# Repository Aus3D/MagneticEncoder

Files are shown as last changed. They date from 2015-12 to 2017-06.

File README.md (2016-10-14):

# MagneticEncoder
## Overview
The magnetic breakout is a breakout PCB for the AMS AS5311 magnetic encoder IC, for testing and development purposes. An external microcontroller is required to track the encoder's position.

The magnetic module combines the features of the breakout board along with an on-board AVR tasked with reading the encoder data and tracking the encoder's position. It exposes the tracked position over an I2C interface.

AMS have now discontinued the AS5311 IC I have been using, so I am switching to the NSE5310 - which I believe AMS intend as a replacement for the AS5311, as it has very similar capabilities. The NSE5310 module is still untested however.

## Open Source
In the spirit of the RepRap project, the magnetic encoder module is fully open source - files to manufacture or modify a board of your own are included in this repository. This project is licensed under a GPLv3 license, and anyone is free to modify it, manufacture it, sell it - as long as you share your modifications under the same license, we're good!

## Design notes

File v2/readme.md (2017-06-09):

## Improvements in V2:

- Full 3V/5V compatibility
  - Power can be either, I2C signals can be either. All combinations are valid, i.e.:
    - 5V Power, 5V I2C
    - 5V Power, 3.3V I2C
    - 3.3V Power, 5V I2C
    - 3.3V Power, 3.3V I2C
  - No solder jumpers to set voltage, works automatically.
- Continuous voltage input range
  - Previously 3.3V-3.6V in 3.3V mode, 4.5-5.5V in 5V mode
  - Now 3.3V – 5.5V, no ‘modes’
- Modules are now ‘Chainable’
  - Each module has 3 JST-SH sockets on board, modules can be daisy-chained to reduce wiring clutter
  - May remove need for splitter boards in some printer layouts
- Overvoltage protection
  - Protected against supply voltages > 5.5V and < 15V, i.e. 12V will not damage the module but it will not operate in this condition.
- Reverse polarity protection
  - Protected against accidentally reversing VDD and GND pins in connector. Reversal will not damage the module but it will not operate in this condition.
- Overcurrent protection
- DIP switches instead of solder jumpers
  - Easy to set module address via switch positions
  - No longer necessary to cut/solder jumpers
  - Easily changeable/reversible
  - Configuration via I2C is still possible if preferred
- Faster on-board microcontroller
  - STM32F030F4P6 instead of ATmega328-AU
  - Possibility for averaging/filtering readings on-board

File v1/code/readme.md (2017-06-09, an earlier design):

The code for the magnetic encoder modules has been moved to its own repository [here](https://github.com/Aus3D/Magnetic-Encoder-Firmware).

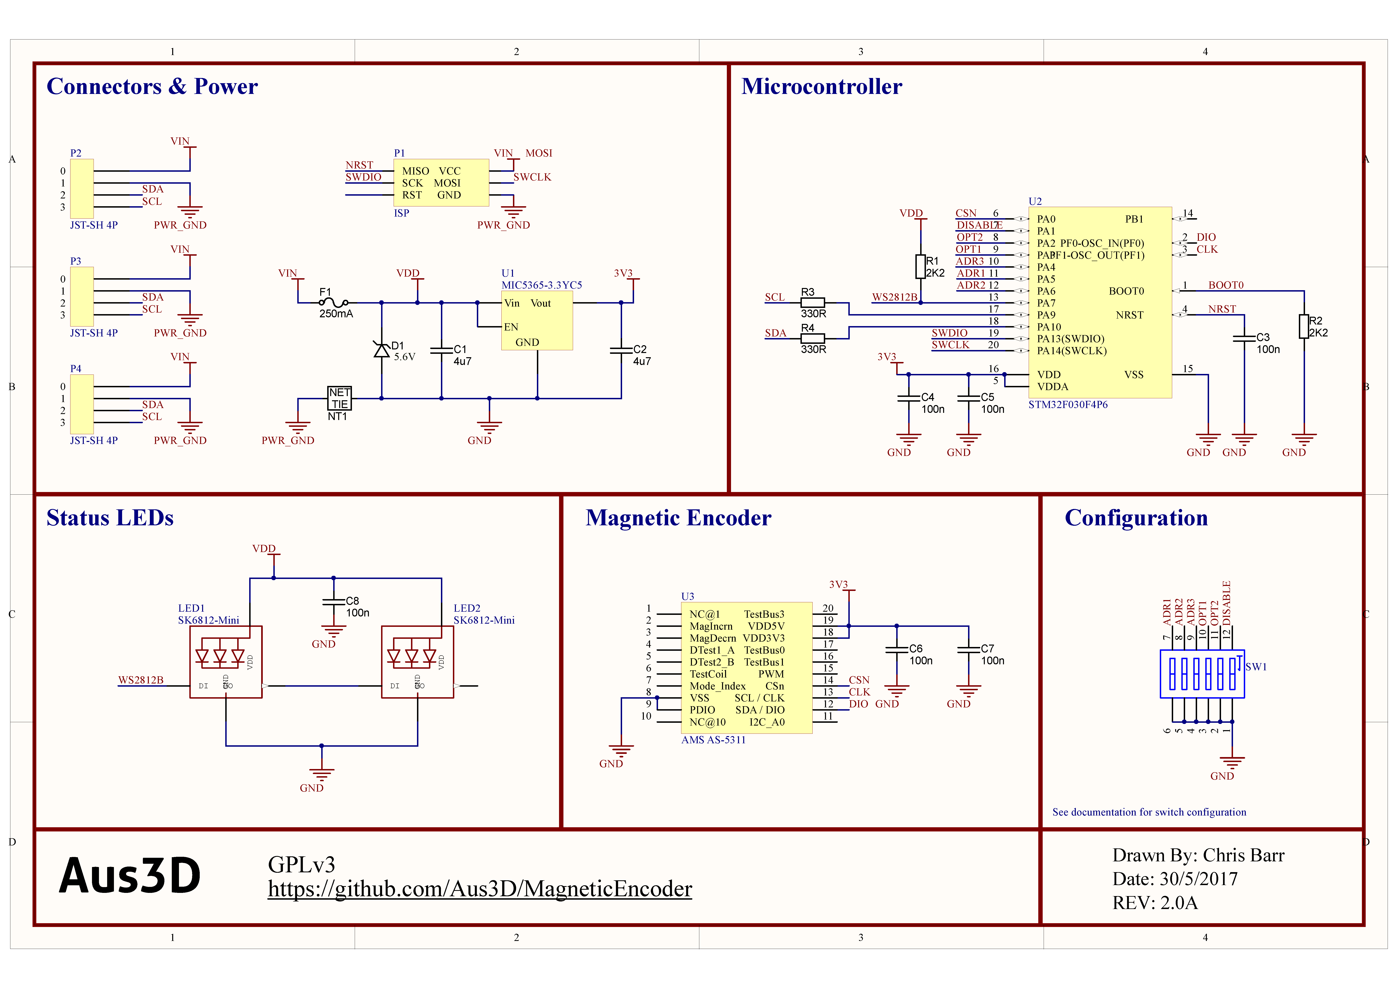
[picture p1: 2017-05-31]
v2/pcb/schematic-mag-encoder-v2.png

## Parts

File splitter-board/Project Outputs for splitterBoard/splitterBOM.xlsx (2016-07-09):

Designator | Description | Comment | Quantity | Manufacturer 1 | Manufacturer Part Number 1 | Supplier 1 | Supplier Part Number 1
P1, P2, P3, P4, P5, P6, P7 | Header, 4-Pin | Approved Sub OK | 7 | 3M (https://octopart-clicks.com/click/altium?sku=3M9447-ND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) | 961104-6404-AR | Digi-Key | 3M9449-ND

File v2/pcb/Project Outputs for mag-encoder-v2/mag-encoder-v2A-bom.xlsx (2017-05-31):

Designator | Description | Comment | Manufacturer 1 | Manufacturer Part Number 1 | Quantity | Supplier 1 | Supplier Part Number 1 | Value
C1, C2 | Capacitor SMD Cer 4.7uF 10% 16V X5R 0603 | Approved sub OK | Samsung Electro-Mechanics America, Inc. | CL10A475KO8NNNC | 2 | Digi-Key | 1276-2087-1-ND | 4u7
C3, C4, C5, C6, C7, C8 | Capacitor SMD Cer 100nF 10% 16V X5R 0402 | Approved sub OK | AVX Corporation | 0402YD104KAT2A | 6 | Digi-Key | 478-1126-1-ND | 100n
D1 | Diode Zener SMD 5.6V 0.5W SOD-123 BZT52C5V6 | Approved sub OK | Diodes Incorporated | BZT52C5V6-7-F | 1 | Digi-Key | BZT52C5V6-FDICT-ND | 5.6V
F1 | Fuse - 15V 100mA Hold 250mA Trip PTC SMD 0603 | Approved sub OK | Bel Fuse Inc. | 0ZCM0010FF2G | 1 | Digi-Key | 507-1818-1-ND | 250mA
LED1, LED2 | RGB Smart LED WS2812 / SK6812 Mini 3535 | SK6812-Mini | DONGGUANG OPSCO OPTOELECTRONICS CO., LTD | SK6812MINI | 2
P2, P3, P4 | JST SH 4P Connector | JST-SH 4P | JST Sales America Inc. | SM04B-SRSS-TB(LF)(SN) | 3 | Digi-Key | 455-1804-1-ND
R1, R2 | Resistor SMD chip 2.2k Ohm 0.063W 5% 0402 | Approved sub OK | Vishay Dale | CRCW04022K20JNED | 2 | Digi-Key | 541-2.2KJCT-ND | 2K2
R3, R4 | Resistor SMD chip 330 Ohm 0.063W 5% 0402 | Approved sub OK | Yageo | RC0402JR-07330RL | 2 | Digi-Key | 311-330JRCT-ND | 330R
SW1 | SMD DIP Switch 1.27mm Pitch 6 Position | Approved sub OK | TE Connectivity ALCOSWITCH Switches | 1571983-9 | 1 | Digi-Key | 450-1950-1-ND
U1 | 3.3V LDO Regulator | MIC5365-3.3YC5 | Microchip Technology | MIC5365-3.3YC5-TR | 1 | Digi-Key | 576-3193-1-ND
U2 | ARM Cortex-M0 32-bit MCU, 16 KB Flash, 4 KB Internal RAM, 15 I/Os, 20-pin TSSOP, -40 to 85 degC, Tube | STM32F030F4P6 | STMicroelectronics (https://octopart-clicks.com/click/altium?sku=511-STM32F030F4P6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) | STM32F030F4P6 (https://octopart-clicks.com/click/altium?sku=511-STM32F030F4P6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) | 1 | Digi-Key | 497-14044-5-ND (https://octopart-clicks.com/click/altium?sku=511-STM32F030F4P6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)
U3 | AMS Linear Magnetic Encoder IC | AMS AS-5311 | ams | AS5311-ATST-500 | 1 | Digi-Key | AS5311-ATST-500CT-ND

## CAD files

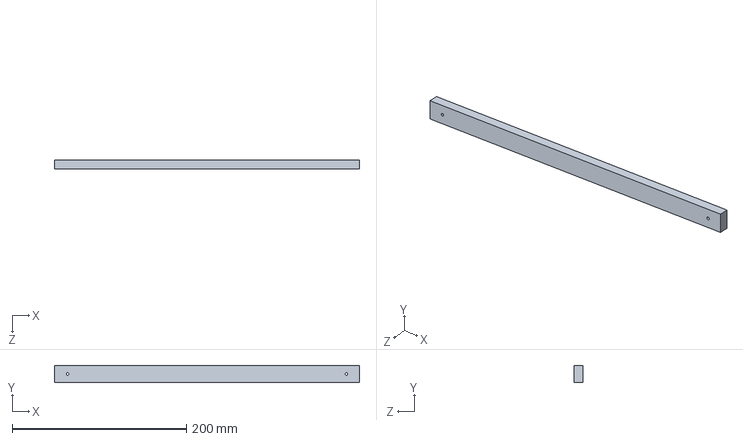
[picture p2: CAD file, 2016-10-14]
hardware/mountingBar.SLDPRT
350.0 x 20.0 x 10.0 mm

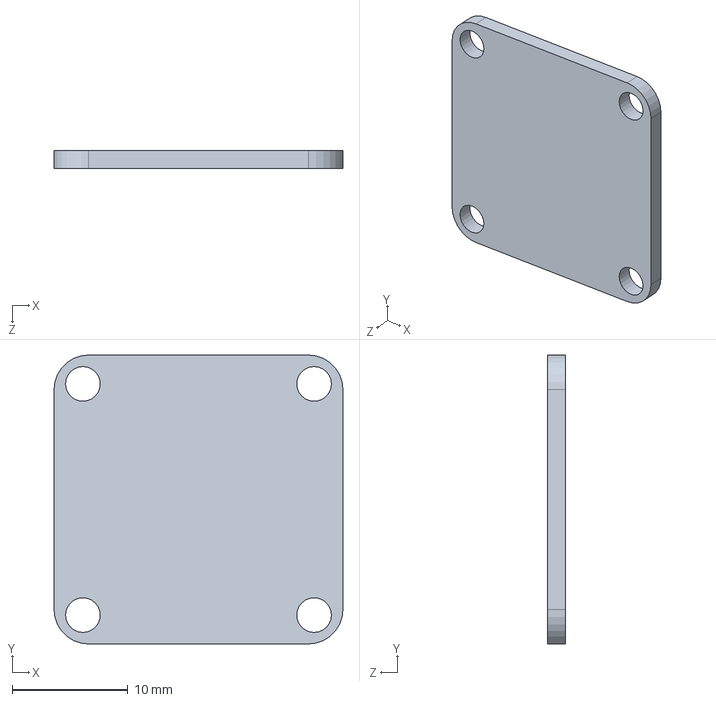
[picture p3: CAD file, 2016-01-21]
hardware/placeholderPart.SLDPRT
25.0 x 25.0 x 1.60 mm

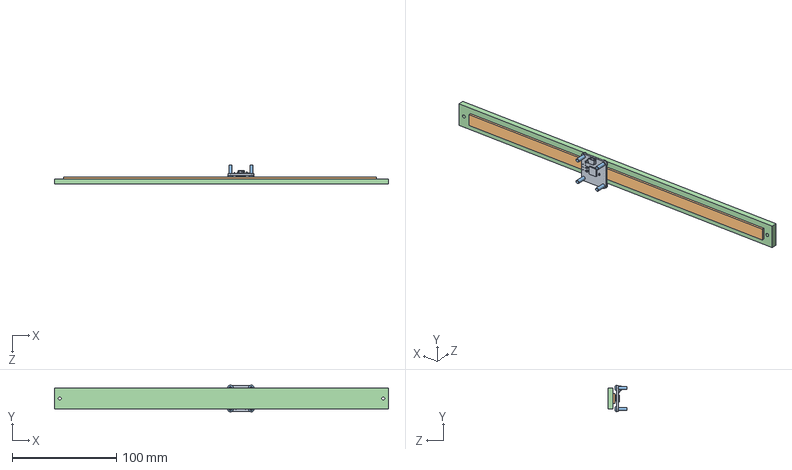
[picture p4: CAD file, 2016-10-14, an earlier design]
v1/nse5310-module-pcb/mounting-demo-assembly.SLDASM
320.0 x 25.7 x 18.5 mm
nse5310-module
mag-strip-placeholder
socket button head screw_iso x 4
mag-strip-support-placeholder

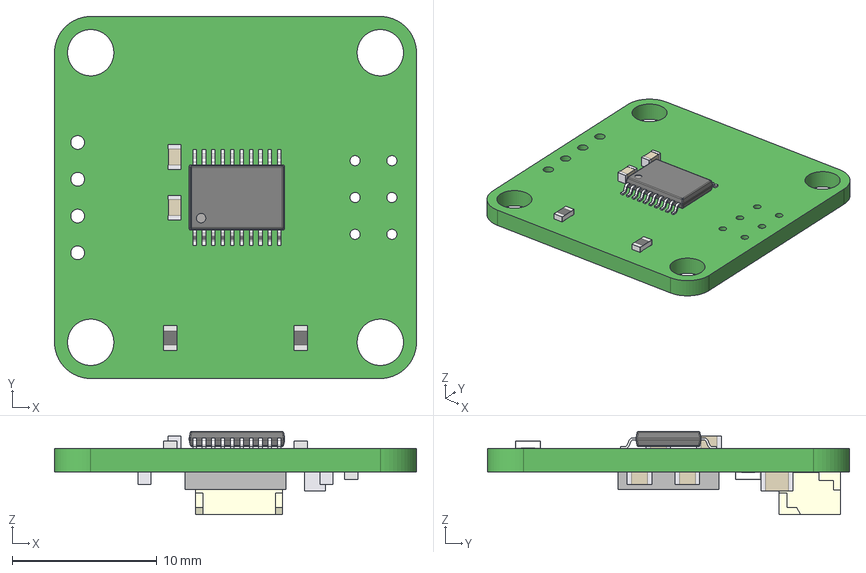
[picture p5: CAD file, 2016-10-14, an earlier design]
v1/nse5310-module-pcb/nse5310-module.step
25.0 x 25.0 x 5.76 mm
Board
RES_0603_(1608_metric) x 3
Extruded
CAP_0603 x 5
SM04B-SRSS-TB_RGB13434879
CAP_0805

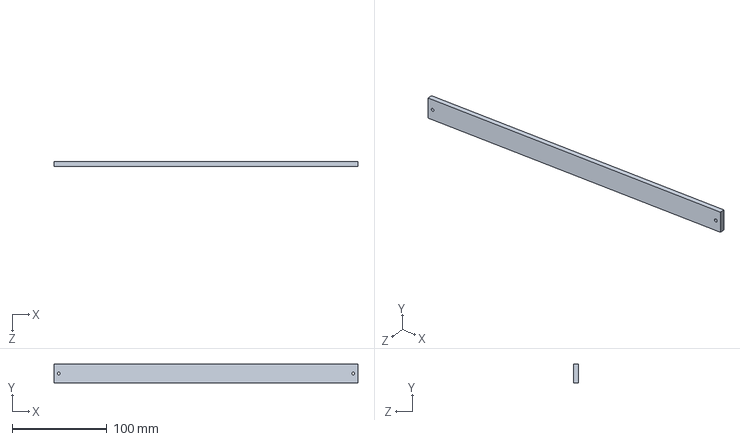
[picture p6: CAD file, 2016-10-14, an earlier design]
v1/nse5310-module-pcb/mag-strip-support-placeholder.SLDPRT
320.0 x 20.0 x 5.00 mm

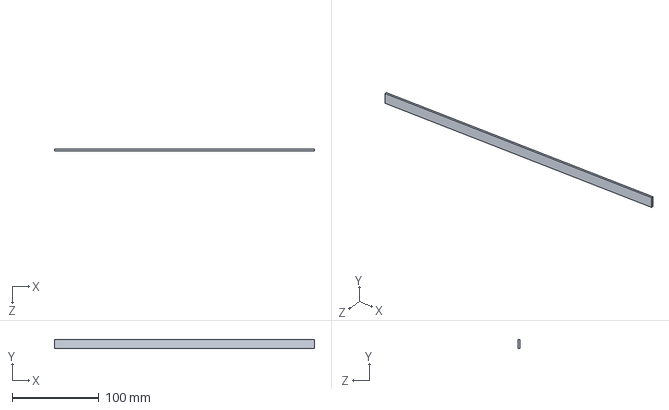
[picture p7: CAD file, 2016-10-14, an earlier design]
v1/nse5310-module-pcb/mag-strip-placeholder.SLDPRT
300.0 x 10.0 x 2.00 mm

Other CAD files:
v1/nse5310-module-pcb/mounting-demo-assembly.SLDDRW
v1/nse5310-module-pcb/nse5310-module.SLDPRT

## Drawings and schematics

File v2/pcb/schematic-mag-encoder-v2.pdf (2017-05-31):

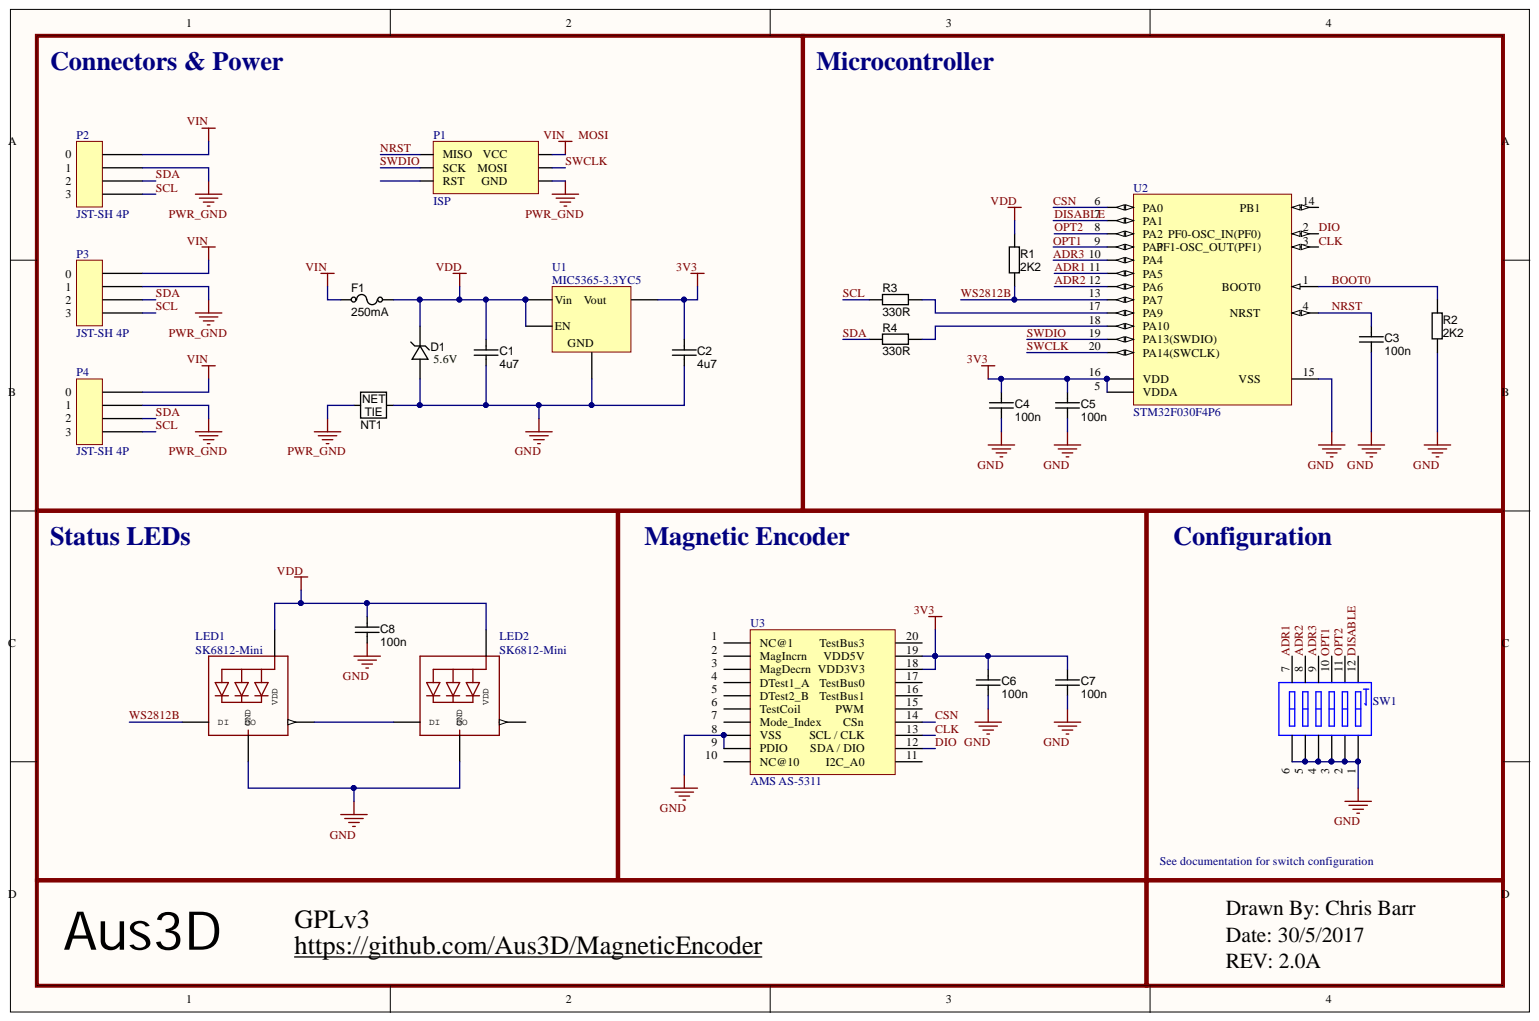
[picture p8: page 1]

SWDIO

See documentation for switch configuration

https://github.com/Aus3D/MagneticEncoder

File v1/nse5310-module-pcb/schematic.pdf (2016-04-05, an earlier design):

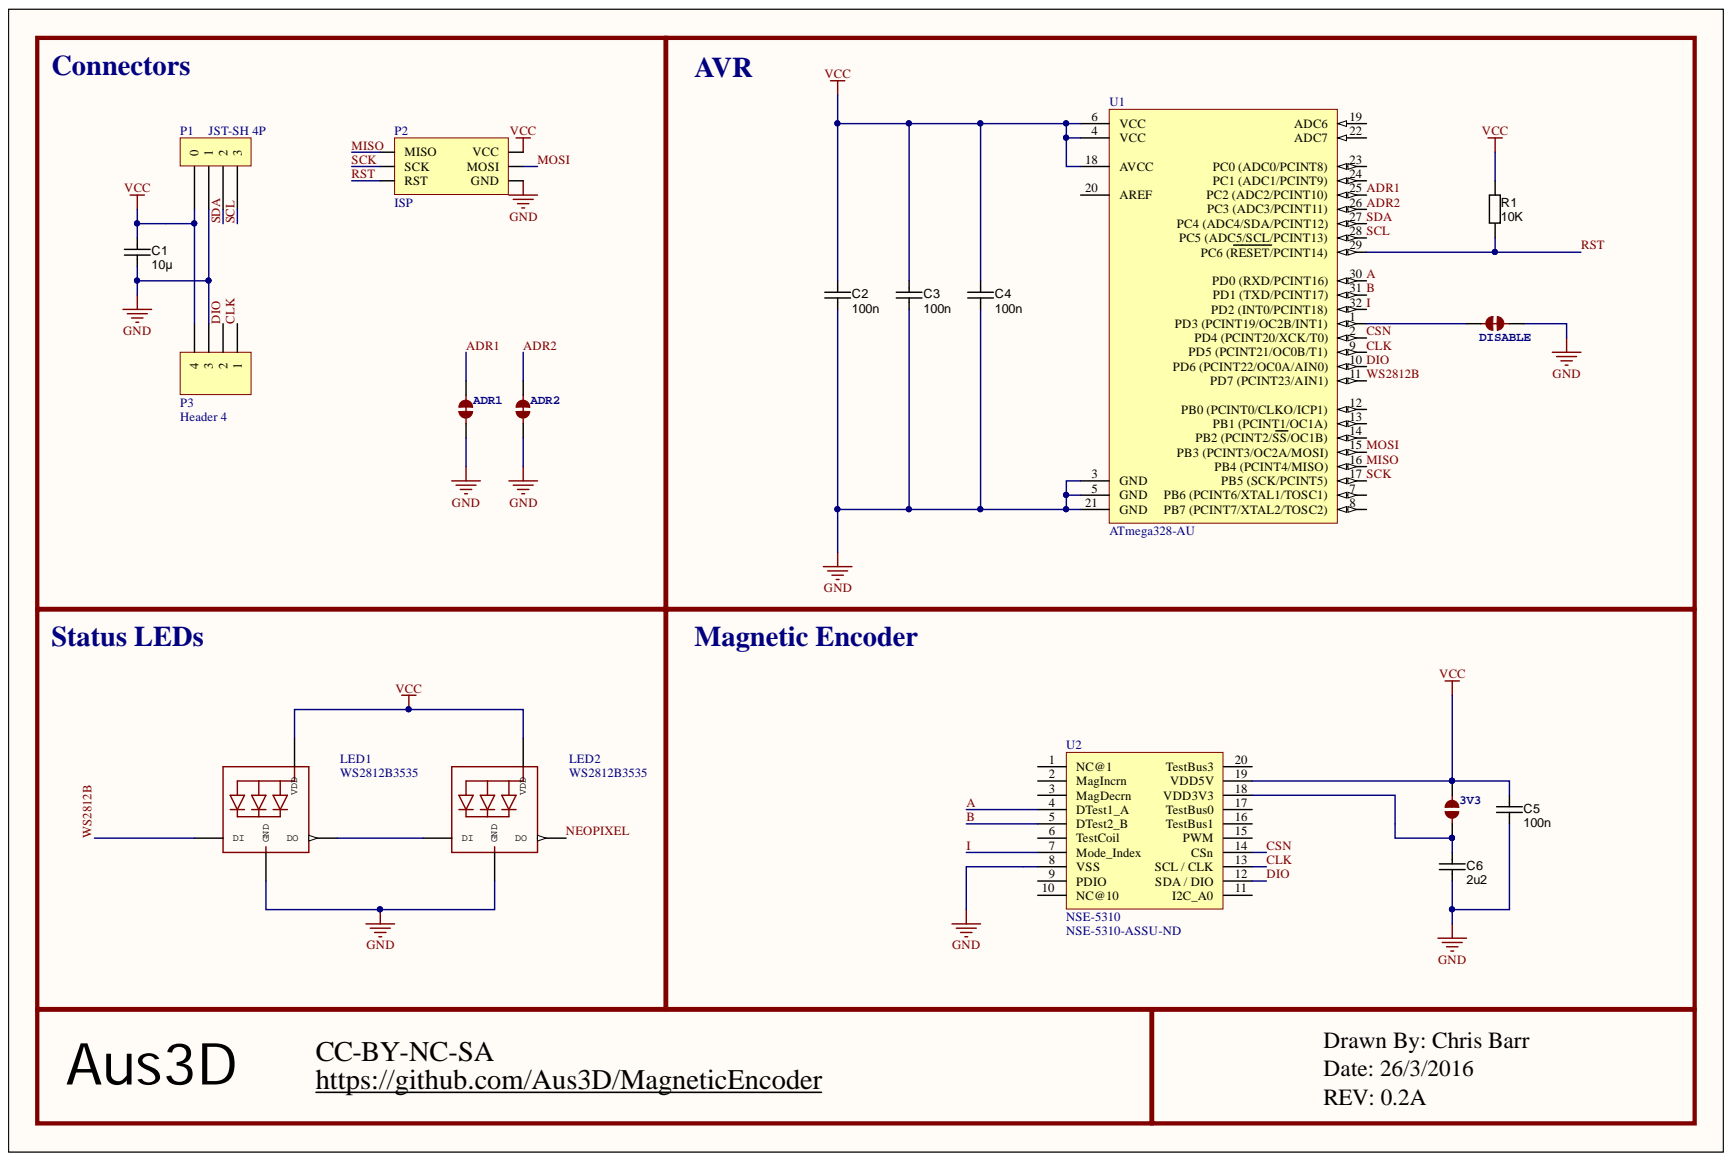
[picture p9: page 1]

P1 JST-SH 4P P2 VCC | VCC

VSS 8
PDIO 9

https://github.com/Aus3D/MagneticEncoder

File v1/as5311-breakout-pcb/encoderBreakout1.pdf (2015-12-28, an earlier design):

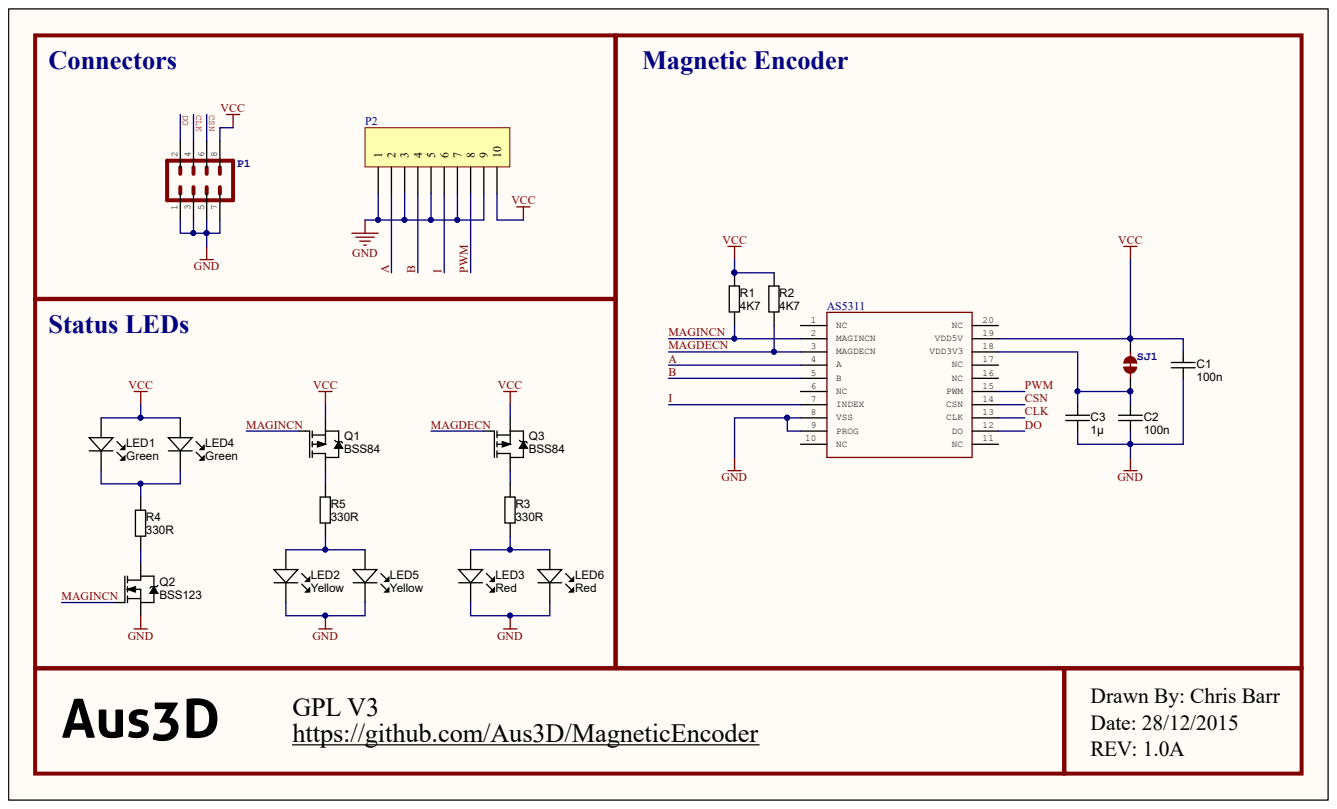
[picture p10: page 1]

https://github.com/Aus3D/MagneticEncoder

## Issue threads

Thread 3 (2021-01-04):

Q - AS5600 magnetic encoder

DrumClock, 2021-01-04:
Hi, is it possible to use this magnetic encoder for Marlin FW?

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

Thanks :)

Fusseldieb, 2021-08-10:
Same question

Fusseldieb, 2022-01-30:
Why did you close the issue @DrumClock ?

DrumClock, 2022-01-30:
Nobody was interested in over a year, so why leave it open ... It doesn't make sense.

jwdriessen, 2022-05-05:
I would love to know how to set this up with marlin 2.0.
I have set up this encoder and try to test it with moving the X motor and holding the axis firmly
I would expect that the encoder makes up for the missed steps but that is not happening.
Is there anyone out there who has this working with a NEMA 17 motor?
Regards JWD

theohenrichs, 2022-06-01:
Hi jwdriessen

Reading https://github.com/MarlinFirmware/Marlin/issues/21138 it seems that Marlin doesn't support this type of position-thing at all anymore .....

Quote from DrumClock @ 21 Feb 2021

> That's probably why Aus3D ended up with the production of its module, and the function in Marlin is just a remnant that is no longer used.

Endquote ...

chrissbarr, 2022-06-26:
Hi all,

Sorry that there's been no proper reply here before.

The AS5600 is a fairly different type of encoder to the one that was used in these modules. I did not write any Marlin firmware feature to support encoders like the AS5600. I had planned to, but do not believe it ever made it to a working state. Others may have done so, but I am unsure.

Additionally, the encoder modules in this repo (and supported by the Marlin code I wrote) were implemented with an onboard AVR microcontroller that managed each encoder IC. The AVR firmware implemented a slave I2C interface that Marlin communicated with (e.g., the Marlin FW never directly touched the encoder IC's I2C interface). This was done because each encoder needed to be read at a higher rate than was practical from the central Marlin FW (it also allowed the use of different I2C addresses, and the implementation of a checksum to add some noise tolerance to the long I2C bus).

So, if you want to directly talk to the AS5600 using I2C from Marlin, you should ignore the work I did previously.

The error correction behaviour itself that I added to Marlin could definitely be adapted to the AS5600 (or any other comparable encoder).

**So, in short, I would say**: there is no reason the AS5600 couldn't be used in Marlin, but the I2C-related code I wrote will not be helpful, and I don't know if anyone else has written something suitable. There may be issues relating to the required update-rate, noise tolerance, and I2C address selection. If the I2C interface can be implemented, the error-correction code I added can likely be adapted. However I don't think there is any simple configuration option to enable the desired behaviour - someone would need to implement it.

Aus3D stopped producing these encoder modules for two reasons:

1. The total cost to upgrade a printer with the linear encoders was quite high (around 60 USD per axis, so say 180 USD per printer) - there did not seem to be a lot of demand at this price point.
2. The encoder IC we were using (NSE5310 or AS5311) went out of stock for over a year and we were unable to produce any more modules.

I hope that sheds some clarity on this topic. Sorry that I'm not adding any positive news here. Happy to answer any further questions though.

Closed 2022-01-30.

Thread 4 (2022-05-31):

M860-M869 - I2C Position Gcode commands

theohenrichs, 2022-05-31:
I have connected an AS5600 magnetic encoder to a Rumba32 board and configured it as mentioned in the configuration-adv.h (Marlin 2.0.9.3).
Carefully I started with only the X. No errors occurred during the building, uploading, and startup of the printer.

When I wanted to check the status of the AS5600 with the Gcode command M862 X, the response of the board was:  **"echo:Unknown command: "M862 X"**
I have tried all **M860-M869 - I2C Position commands**, but each time the answer is: **"echo:Unknown command"**.
I double checked the connections "+, -, D and C" both on the board and on the AS5600.

However, something is wrong here, is it that the **AS5600 is NOT compatible**, or is there perhaps a **bug in this Marlin version**?

Anyone have an idea what's going on here? Help is greatly appreciated!

theohenrichs, 2022-05-31:
Oh dear!
Reading https://github.com/MarlinFirmware/Marlin/issues/21138  it seems that Marlin doesn't support this type of position-thing at all anymore .....

Quote from DrumClock @ 21 Feb 2021

_> That's probably why Aus3D ended up with the production of its module, and the function in Marlin is just a remnant that is no longer used._

Endquote ...

Closed 2022-05-31.

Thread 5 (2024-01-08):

Closed loop doesn't work

RbAstra, 2024-01-08:
Hello

I want to control 3 axis by sending Grbl commands in the USB port by using pronterface software. I succeed to move every axis but I need to be sure of the position (closed loop).
So I rebuild 3 magnetic encoders (V1 with Atmega) by using the manufacturing files and soldering components on the PCB. I made some tests with the encoders and I can measure the position of the system but it didn't work in closed loop.
This is what I've done to verify closed loop function:
1. I send a GRBL command to make relative positioning -> G91 G0 X100
2. I block the system during movement (just like the video at the bottom of the encoder wiki)
3. Thanks to magnetic encoder I measure position in ticks at the end of movement and the reached distance was 97mm instead of 100mm

When I enable the correction (M867 command) it responds the correction is enabled for all axis. However it doesn't correct the position.

Does Somebody know why ?

RbAstra, 2024-01-08:
I'm using Marlin 2.1.2.1

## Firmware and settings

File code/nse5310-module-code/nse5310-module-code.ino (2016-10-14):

/*
/---------------------------------------------------------------/
 * Code for the Aus3D NSE5310 Magnetic Encoder I2C Module
 * Chris Barr, 2016
 * 
 * This module is designed to connect to a host device via I2C,
 * and report the current position as observed by the magnetic encoder.
 * 
 * The following I2C commands are implemented:
 *    
 * 1: Resets travelled distance to zero
 * 
 * 2: Sets this modules I2C address to the next byte received, 
 *    saves in EEPROM
 *    Module resets and rejoins bus with new address
 *    
 * 3: Set the information that will be sent on the next I2C request.
 *      0: Default, responds with encoder count
 *      1: Responds with magnetic signal strength
 *            0: Signal good, in range.
 *            1: Signal weak, edge of range (but probably usable)
 *            2: Signal weak / lost, edge / outside of range (probably not usable)
 *      2: Responds with firmware version + compile date / time
 *      3: Responds with raw encoder reading
 *
 * 4: Clear the settings saved in EEPROM, restoring all defaults
 *      Handy to return to hardware I2C address if required
 *      A power cycle will be required for settings to reset
 *
 * 10: Sets the mode of the LEDs based on the next two bytes received, 
 *     byte1 = led (0 or 1), byte 2 = mode (see below)
 *     saves in EEPROM
 *
 * 11: Sets the brightness of the LEDs based on the next two bytes received,
 *    byte1 = led (0 or 1), byte 2 = brightness (0-255)
 *    saves in EEPROM
 *
 * 12: Sets the RGB value for the LEDs to the next three bytes received,
 *     LEDs must still be set to RGB mode to display the sent value.
 *
 * 13: Sets the HSV value for the LEDs to the next three bytes received,
 *     LEDs must still be set to HSV mode to display the sent value.
 *
 * 14: Set the rate variable of the LEDs based on the next two bytes received,
 *      Rate is used in some of the different LED modes
 * 
 * I2C address can either be set over I2C (as shown above), or configured by cutting jumper traces on PCB.
 * If the address has been set by I2C, it can only be overridden by setting a new address over I2C, or by
 * sending the I2C command to reset the EEPROM.
 * 
 * 0 = default
 * 1 = trace cut
 * 
 * ADR1 ADR2 |  Mode
 *  0    0   |   X      //Default
 *  0    1   |   Y
 *  1    0   |   Z
 *  1    1   |   E
 *  
 *  LED Modes:
 *  
 *  0     Status indication of magnetic field
 *  1     Solid White
 *  2     Solid Red
 *  3     Solid Green
 *  4     Solid Blue
 *  5     RGB Value
 *  6     HSV Value
 *  7     Party Mode 1
 *  8     Party Mode 2
 *              
 /---------------------------------------------------------------/
 */
#include <Wire.h>
#include <SoftwareWire.h>
#include <EEPROM.h>
#include "FastLED.h"
#include <avr/wdt.h>

#define SCHEMA 5
#define FIRMWARE_VERSION "1.0.0"

#define PIXEL_PIN   7
#define PIXEL_NUM   2

#define DISABLE_PIN 3

//Encoder Setup
#define ENC_SELECT_PIN  4
#define ENC_CLOCK_PIN   5
#define ENC_DATA_PIN    6
#define ENC_ADDR 0b1000000

SoftwareWire encWire( ENC_DATA_PIN, ENC_CLOCK_PIN, true, true);

//I2C Slave Setup
#define ADDR1_PIN   16
#define ADDR2_PIN   17

//I2C Defines
#define I2C_MAG_SIG_GOOD  0
#define I2C_MAG_SIG_MID   1
#define I2C_MAG_SIG_BAD   2

#define I2C_REPORT_POSITION   0
#define I2C_REPORT_STATUS     1
#define I2C_REPORT_VERSION    2
#define I2C_REPORT_RAW        3

#define I2C_REQ_REPORT        0
#define I2C_RESET_COUNT       1
#define I2C_SET_ADDR          2
#define I2C_SET_REPORT_MODE   3
#define I2C_CLEAR_EEPROM      4

#define I2C_ENC_LED_PAR_MODE  10
#define I2C_ENC_LED_PAR_BRT   11
#define I2C_ENC_LED_PAR_RATE  12
#define I2C_ENC_LED_PAR_RGB   13
#define I2C_ENC_LED_PAR_HSV   14

//default I2C addresses
#define I2C_ENCODER_PRESET_ADDR_X 30
#define I2C_ENCODER_PRESET_ADDR_Y 31
#define I2C_ENCODER_PRESET_ADDR_Z 32
#define I2C_ENCODER_PRESET_ADDR_E 33
#define I2C_UNALLOCATED_ADDRESS   0

#define MAG_GOOD_RANGE 4
#define I2C_READ_BYTES 4

const byte i2c_base_address = I2C_ENCODER_PRESET_ADDR_X;
byte i2c_address;
int i2c_response_mode = 0;

//#define SERIAL_ENABLED

//EEPROM Setup
#define EEPROM_USED_SIZE 24 //used to only clear first X bytes on initialisation. Faster than clearing whole EEPROM.
#define EEPROM_I2C_ADDR 1
#define EEPROM_BRT1_ADDR 2
#define EEPROM_BRT2_ADDR 3
#define EEPROM_MODE1_ADDR 4
#define EEPROM_MODE2_ADDR 5
#define EEPROM_RATE1_ADDR 6
#define EEPROM_RATE2_ADDR 7
#define EEPROM_SLP1_ADDR 8
#define EEPROM_SLP2_ADDR 9
#define EEPROM_RGB1_ADDR 10
#define EEPROM_RGB2_ADDR 11
#define EEPROM_RGB3_ADDR 12
#define EEPROM_HSV1_ADDR 13
#define EEPROM_HSV2_ADDR 14
#define EEPROM_HSV3_ADDR 15

typedef union {
    volatile long val;
    byte bval[4];
}i2cLong;

i2cLong encoderCount;
i2cLong rawCount;

long count = 0;
long oldCount = 0;
long revolutions = 0;
long offset = 0;
bool offsetInitialised = false;
long avgSpeed = 0;

float mm = 0;
float oldMm = -999;
float prevMm = 0;

bool OCF = false;
bool COF = false;
bool LIN = false;
bool mINC = false;
bool mDEC = false;

byte magStrength = I2C_MAG_SIG_BAD;

unsigned long lastLoopTime = 0;

byte addressOffset;

int ledBrightness[] = {20,20};
int ledMode[]       = {0,0};
int ledRate[]       = {0,0};
int ledSleep[]      = {0,0};

byte ledRGB[] = {255,0,0};
byte ledHSV[] = {255,255,255};

CRGB leds[PIXEL_NUM];

// This function is called upon a HARDWARE RESET:
void wdt_first(void) __attribute__((naked)) __attribute__((section(".init3")));
 
// Clear SREG_I on hardware reset. Make sure watchdog is disabled on new boot.
void wdt_first(void) {
  MCUSR = 0; // clear reset flags
  wdt_disable();
}

void setup() {
  #ifdef SERIAL_ENABLED
    Serial.begin(250000);
    Serial.println("Serial comms initialised");
  #endif

  //Configure pins
  pinMode(ENC_SELECT_PIN, OUTPUT);
  pinMode(ADDR1_PIN,INPUT_PULLUP);
  pinMode(ADDR2_PIN,INPUT_PULLUP);
  pinMode(DISABLE_PIN,INPUT_PULLUP);

  //Configure LEDs
  FastLED.addLeds<NEOPIXEL, PIXEL_PIN>(leds, PIXEL_NUM);
  FastLED.setBrightness(100);

  //Check reset pin for permanent disable
  if(digitalRead(DISABLE_PIN) == LOW) {
    //crude debounce
    delay(100);
    if(digitalRead(DISABLE_PIN) == LOW) {
      //Set enc_select low to enable encoder I2C with external controller
      digitalWrite(ENC_SELECT_PIN, LOW);
      blinkLeds(1,CRGB::White);
      //Halt startup and never proceed
      while(true);
    }
  }

  //Initialise communication with encoder IC
  if(initEncoder() == false) {
    #ifdef SERIAL_ENABLED
      Serial.print("Encoder Init Failed!");
    #endif

    while(initEncoder() == false) {
     blinkLeds(1,CRGB::Red); 
    }
  } else {
    blinkLeds(1,CRGB::Green);
  }

  //Read address pins as 2-bit number
  addressOffset = digitalRead(ADDR1_PIN) + 2*(digitalRead(ADDR2_PIN));

  //Set I2C address from value
  i2c_address = i2c_base_address + addressOffset;

  #ifdef SERIAL_ENABLED
    Serial.print("I2C Address: ");
    Serial.println(i2c_address);
  #endif

  //Initialise EEPROM if first boot, otherwise read stored values
  if (EEPROM.read(0) != SCHEMA) {
    reinitialize();
    EEPROM.write(0, SCHEMA);
    eepromLoad();
    blinkLeds(1,CRGB::Purple);
  } else {
    eepromLoad();
    blinkLeds(1,CRGB::Green);
  }

  //If a custom I2C address has been saved in EEPROM, 
  //it has now overridden the hardware value

  //Signal I2C address
  if(i2c_address >= I2C_ENCODER_PRESET_ADDR_X && i2c_address <= I2C_ENCODER_PRESET_ADDR_E) {
    switch (i2c_address) {
      case I2C_ENCODER_PRESET_ADDR_X:
        blinkLeds(1,CRGB::Blue);
        break;
      case I2C_ENCODER_PRESET_ADDR_Y:
        blinkLeds(1,CRGB::Yellow);
        break;
      case I2C_ENCODER_PRESET_ADDR_Z:
        blinkLeds(1,CRGB::Green);
        break;
      case I2C_ENCODER_PRESET_ADDR_E:
        blinkLeds(1,CRGB::Magenta);
        break;
    }
  } else {
    blinkLeds(1,CRGB::White);
  }
  
  delay(50);

  //Join I2C bus as slave
  Wire.begin(i2c_address);
  Wire.onRequest(requestEvent);
  Wire.onReceive(receiveEvent);
}

void loop() {
  updateEncoder();
  updateLeds();
  watchResetPin();
}

void updateLeds() {
  for(int i = 0; i < PIXEL_NUM; i++) {
    switch (ledMode[i]) {
      case 0:
        if(magStrength == I2C_MAG_SIG_GOOD) { 
          leds[i] = CRGB::Green; 
        } else if(magStrength == I2C_MAG_SIG_MID) { 
          leds[i] = CRGB::Yellow; 
        } else if(magStrength == I2C_MAG_SIG_BAD) {
          leds[i] = CRGB::Red; 
        }
        break;
      case 1:
        leds[i] = CRGB::White;
        break;
      case 2:
        leds[i] = CRGB::Red;
        break;
      case 3:
        leds[i] = CRGB::Green;
        break;
      case 4:
        leds[i] = CRGB::Blue;
        break;
      case 5:
        leds[i].setRGB(ledRGB[0],ledRGB[1],ledRGB[2]);
        break;
      case 6:
        leds[i].setHSV(ledHSV[0],ledHSV[1],ledHSV[2]);
        break;
      case 7:
        leds[i].setHSV(encoderCount.val/10*ledRate[i],255,255);
        break;
      case 8:
        leds[i].setHSV(millis()/1000*ledRate[i],255,255);
        break;
    }
    leds[i].nscale8(ledBrightness[i]);
  }
  FastLED.show();
}

void blinkLeds(int times, const CRGB& rgb) {
  for(int i = 0; i < times; i++) {  
    for(int j = 0; j < PIXEL_NUM; j++) {
      leds[j] = rgb;
      leds[j].nscale8(20);
    }
    FastLED.show();
    delay(500);
    for(int j = 0; j < PIXEL_NUM; j++) {
      leds[j] = CRGB::Black;
      leds[j].nscale8(ledBrightness[j]);
    }
    FastLED.show();
    delay(500);
  }
}

////////////////////////////////////////////////////////////
//----------------------- I2C ----------------------------//
////////////////////////////////////////////////////////////

void requestEvent() {
  switch (i2c_response_mode) {
    case I2C_REPORT_POSITION:
      Wire.write(encoderCount.bval,4);
      break;
    case I2C_REPORT_STATUS:
      Wire.write(magStrength);
      break;
    case I2C_REPORT_VERSION:
      reportVersion();
      break;
    case I2C_REPORT_RAW:
      rawCount.val = count;
      Wire.write(rawCount.bval,4);
      break;
  }
}

void receiveEvent(int numBytes) {

  byte temp[5] = {0};
  int tempIndex = 0;

  while(Wire.available() > 0) {
    temp[tempIndex] = Wire.read();
    tempIndex++;
  }

  switch(temp[0]) {
    case I2C_RESET_COUNT:
      offset = encoderCount.val;
      break;
    case I2C_SET_ADDR:
      setI2cAddress(temp[1]);
      blinkLeds(1,CRGB::White);
      restart();
      break;
    case I2C_SET_REPORT_MODE:
      i2c_response_mode = temp[1];
      break; 
    case I2C_CLEAR_EEPROM:
      eepromClear();
      break; 
    case I2C_ENC_LED_PAR_MODE:
      setLedMode(temp[1],temp[2]);
      break;
    case I2C_ENC_LED_PAR_BRT:
      setLedBrightness(temp[1],temp[2]);
      break;  
    case I2C_ENC_LED_PAR_RGB:
      setLedRGB(temp[1],temp[2],temp[3]);
      break;   
    case I2C_ENC_LED_PAR_HSV:
      setLedHSV(temp[1],temp[2],temp[3]);
      break;   
    case I2C_ENC_LED_PAR_RATE:
      setLedRate(temp[1],temp[2]);
      break;    
  }  
}

void reportVersion() {
  // example: 1.0.0, Jul 15 2016, 21:07:40
  String versionString = FIRMWARE_VERSION ", " __DATE__ ", " __TIME__ ".";
  Wire.write(versionString.c_str());
}

////////////////////////////////////////////////////////////
//--------------------- ENCODER --------------------------//
////////////////////////////////////////////////////////////
bool initEncoder() {
  encWire.begin();

  //read a test byte
  digitalWrite(ENC_SELECT_PIN, LOW);
  encWire.requestFrom(ENC_ADDR,1,true);

  int data = encWire.read();
  
  digitalWrite(ENC_SELECT_PIN, HIGH);

  if(data == -1) {
    return false;
  } else {
    return true;
  }
}

void updateEncoder() {
  count = readPosition();

  //check if we've moved from one pole-pair to the next
  if((count-oldCount) > 2048) {
    revolutions -= 1;
  } else if((oldCount - count) > 2048) {
    revolutions += 1;
  }

  oldCount = count;

  //make the starting position 'zero'
  if(offsetInitialised == false) {
    offset = -count;
    offsetInitialised = true;
  }

  encoderCount.val = (revolutions * 4092) + (count + offset);
}

int readPosition() {
  unsigned int position = 0;

  //read in our data  
  digitalWrite(ENC_SELECT_PIN, LOW);
  encWire.requestFrom(ENC_ADDR,I2C_READ_BYTES,true);

  byte b[I2C_READ_BYTES];

  encWire.readBytes(b,5);

  digitalWrite(ENC_SELECT_PIN, HIGH);

  //get our position variable
  position = b[0];
  position = position << 8;

  position |= b[1];
  position = position >> 4;

  byte mIncrDecr      = bitRead(b[1],0);
  byte linAlarm       = bitRead(b[1],1);
  byte cordicOverflow = bitRead(b[1],2);
  byte offsetComp     = bitRead(b[1],3);

  //determine magnetic signal strength
  if(b[3] >= (0x3F-MAG_GOOD_RANGE) && b[3] <= (0x3F+MAG_GOOD_RANGE)) { 
    magStrength = I2C_MAG_SIG_GOOD; 
  } else if(b[3] >= 0x20 && b[3] <= 0x5F) { 
    magStrength = I2C_MAG_SIG_MID; 
  } else if(b[3] < 0x20 || b[3] > 0x5F) { 
    magStrength = I2C_MAG_SIG_BAD; 
  }

  return position;
}

////////////////////////////////////////////////////////////
//---------------------- EEPROM --------------------------//
////////////////////////////////////////////////////////////

void reinitialize() {
  #ifdef SERIAL_ENABLED
    Serial.println("Resetting EEPROM");
  #endif

  eepromClear();
  setI2cAddress(I2C_UNALLOCATED_ADDRESS);

  for(int i = 0; i < 2; i++) {
    setLedBrightness(i,ledBrightness[i]);
    setLedMode(i,ledMode[i]);
    setLedRate(i,ledRate[i]);
    setLedSleep(i,ledSleep[i]);
  }

  setLedRGB(ledRGB[0],ledRGB[1],ledRGB[2]);
  setLedHSV(ledHSV[0],ledHSV[1],ledHSV[2]);
}

void eepromLoad() {
  #ifdef SERIAL_ENABLED
    Serial.println("Loading EEPROM");
  #endif
  
  byte tempAddress = EEPROM.read(EEPROM_I2C_ADDR);

  //check that a value has actually been set,
  //otherwise we use the hardware setting
  if(tempAddress != I2C_UNALLOCATED_ADDRESS) 
    i2c_address = tempAddress; 

  ledMode[0] = EEPROM.read(EEPROM_MODE1_ADDR);
  ledMode[1] = EEPROM.read(EEPROM_MODE2_ADDR);
  ledBrightness[0] = EEPROM.read(EEPROM_BRT1_ADDR);
  ledBrightness[1] = EEPROM.read(EEPROM_BRT2_ADDR);
  ledRate[0] = EEPROM.read(EEPROM_RATE1_ADDR);
  ledRate[1] = EEPROM.read(EEPROM_RATE2_ADDR);
  ledSleep[0] = EEPROM.read(EEPROM_SLP1_ADDR);
  ledSleep[1] = EEPROM.read(EEPROM_SLP2_ADDR);
  ledRGB[0] = EEPROM.read(EEPROM_RGB1_ADDR);
  ledRGB[1] = EEPROM.read(EEPROM_RGB2_ADDR);
  ledRGB[2] = EEPROM.read(EEPROM_RGB3_ADDR);
  ledHSV[0] = EEPROM.read(EEPROM_HSV1_ADDR);
  ledHSV[1] = EEPROM.read(EEPROM_HSV2_ADDR);
  ledHSV[2] = EEPROM.read(EEPROM_HSV3_ADDR);
}

void setI2cAddress(byte i2cAddress) {
  EEPROM.put(EEPROM_I2C_ADDR, i2cAddress);
}

void setLedBrightness(byte led, byte brightness) {
  ledBrightness[constrain(led,0,1)] = brightness;
  EEPROM.put(EEPROM_BRT1_ADDR, ledBrightness[0]);
  EEPROM.put(EEPROM_BRT2_ADDR, ledBrightness[1]);
}

void setLedMode(byte led, byte mode) {
  ledMode[constrain(led,0,1)] = mode;
  EEPROM.put(EEPROM_MODE1_ADDR, ledMode[0]);
  EEPROM.put(EEPROM_MODE2_ADDR, ledMode[1]);
}

void setLedRate(byte led, byte rate) {
  ledRate[constrain(led,0,1)] = rate;
  EEPROM.put(EEPROM_RATE1_ADDR, ledRate[0]);
  EEPROM.put(EEPROM_RATE2_ADDR, ledRate[1]);
}

void setLedSleep(byte led, byte sleep) {
  ledSleep[constrain(led,0,1)] = sleep;
  EEPROM.put(EEPROM_SLP1_ADDR, ledSleep[0]);
  EEPROM.put(EEPROM_SLP2_ADDR, ledSleep[1]);
}

void setLedRGB(byte red, byte green, byte blue) {
  ledRGB[0] = red;
  ledRGB[1] = green;
  ledRGB[2] = blue;
  EEPROM.put(EEPROM_RGB1_ADDR, ledRGB[0]);
  EEPROM.put(EEPROM_RGB2_ADDR, ledRGB[1]);
  EEPROM.put(EEPROM_RGB3_ADDR, ledRGB[2]);
}

void setLedHSV(byte hue, byte sat, byte val) {
  ledHSV[0] = hue;
  ledHSV[1] = sat;
  ledHSV[2] = val;
  EEPROM.put(EEPROM_HSV1_ADDR, ledHSV[0]);
  EEPROM.put(EEPROM_HSV2_ADDR, ledHSV[1]);
  EEPROM.put(EEPROM_HSV3_ADDR, ledHSV[2]);
}

void eepromClear() {
  for (int i = 0; i < EEPROM_USED_SIZE; i++) {
    EEPROM.write(i,0);
  }
}

////////////////////////////////////////////////////////////
//---------------------- SERIAL --------------------------//
////////////////////////////////////////////////////////////
void updateSerial() {
  #ifdef SERIAL_ENABLED
    if(Serial.available() > 0) {
      if(Serial.read() == 'r' || Serial.read() == 'R') {
        revolutions = 0;
        offset = -count;
        Serial.println("Resetting offset...");
      }
    }

    Serial.print(count);
    Serial.print("\t");
    Serial.print(mm,3);
    Serial.print("\t");
    Serial.print(revolutions);
    Serial.println(":");
    Serial.print((revolutions * 4092) + (count + offset));
    Serial.println();
    //lastSerialTime = millis();
    oldMm = mm;

  #endif
}

////////////////////////////////////////////////////////////
//------------------------ MISC --------------------------//
////////////////////////////////////////////////////////////

void watchResetPin() {
  //check reset pin
  if(digitalRead(DISABLE_PIN) == LOW) {
    //crude debounce
    delay(100);
    if(digitalRead(DISABLE_PIN) == LOW) {
      //blink LEDs, if still shorted after this reset
      blinkLeds(5,CRGB::White);
      if(digitalRead(DISABLE_PIN) == LOW) {
        reinitialize();
        blinkLeds(1,CRGB::Green);
        restart();
      }
    }
  }
}

//enable the watchdog timer and loop infinitely to trigger a reset
void restart() {
  encWire.end();
  delay(10);
  wdt_enable(WDTO_250MS);
  for(;;);
}

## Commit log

2015-12-28 Encoder Breakout
    Initial breakout board for testing AS5311 encoder
    [encoderBreakout1.PcbDoc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]
2016-01-21 AS5311 Module
    Module board with integrated AVR to handle I2C comms with main control board.
    [as5311-module.CSV, as5311-module.PcbDoc, as5311-module.PrjPcb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]
2016-01-29 AS5311 Module Update
    Changed to ATtiny20 for smaller size and I2C slave capabilities. Smaller RGB LED. Sent new boards to fab house, hopefully will be testing shortly.
    [Pick Place for as5311-module.csv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]
2016-02-02 AS5311 Module Update
    Changed again. Keep going back and forth between a ATtiny and ATmega IC. The ATtiny20 seemed like a good choice for the previous design, but it doesn't program via ISP, so I need to redo the board anyway. Price-wise an ATmega328 is almost the same, but much more headroom for future changes. IDK.
    [as5311-module.PcbDoc, as5311-module.SchDoc]
2016-02-12 Test Hardware
    3D printed parts to mount encoder breakout and magnetic strip to Mark2 printers.
    [placeholderBracket.SLDPRT, placeholderBracket.STL, xEndBracket.SLDPRT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]
2016-02-12 Manufacturing Files
    PCB gerbers for V0.3 (ATmega328P)
    [as5311-module.GBL, as5311-module.GBO, as5311-module.GBP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]
2016-03-02 Code
    Working for prototype encoder module, still a work in progress though.
    I2C, SSI and RGB LEDs are working. Need to test and expand I2C commands.
2016-03-05 Code Rework
    Tidying, refactoring, expanding LED capabilities (both individually
    controllable), etc.
    Requires further work and testing.
    [Configuration.h, Configuration_adv.h, Marlin Logo_old.dxf]
2016-03-05 Code Rework Continued
    Fleshed out I2C commands and LED modes, tested and corrected issues
    here.
    LED modes work correctly, both LEDs are individually configurable. I2C
    address setting over I2C tested and working. EEPROM saving / loading
    tested and working.
    Quick test of maximum travel speed, module is happy keeping track up to
    300mm/s, over 350mm/s it seems some steps are missed - possibly an
    aliasing effect in the forward/backwards ‘revolution’ counter.
    Problem is worsened (max speed lowered) when the loop timing function
    is running and regulating the loop time, so it’s likely that the only
    way to get better performance is to lower the time each loop takes.
    Maybe split LED commands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
    [UnoHostSketch.ino]
2016-03-05 Change Magnetic Status Output
    Change output to align with LED behaviour, makes it easier to check on
    I2C master.
2016-04-05 New module, tidying
    New module based on AMS' NSE5310 encoder IC. Also tidying / reorganising, moved code to separate folder (most of it will be common to AS5311 and NSE5310 modules).
    [Configuration.h, Configuration_adv.h, Marlin Logo_old.dxf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]
2016-05-11 Module 1.0B
    Added pull-up resistors, manufacturing files for 1.0B
    [magEncoder1B-bom.xlsx, magEncoder1B-pickplace.csv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]
2016-05-12 NSE5310 Code
    Code for Encoder Modules 1.0A and 1.0B using the AMS NSE5310 magnetic
    encoder modules.
2016-05-15 Tidying Folders
    [Configuration.h, Configuration_adv.h, Marlin Logo_old.dxf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]
2016-06-25 Mounting dimensions
    Adding additional dimensions to board layout
    [nse5310-module.PcbDoc, nse5310-module.step]
2016-07-09 I2C Splitter Board
    [splitterBOM.xlsx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]
2016-07-10 Startup LED sequence
    Updating LED sequence to match documentation
2016-07-10 Add disable / reset functionality
    [nse5310-module-code.ino]
2016-07-10 Change z-axis indicator colour
    Yellow for Y and orange for Z were hard to distinguish.
2016-07-15 Fix reset on address change, version info
    [nse5310-module-code.ino]
2016-07-17 Change unallocated I2C address
    Replace magic ’99’ address number with a define set to 0. Cleans code
    and makes address 99 available for use.
    [nse5310-module-code.ino]
2016-07-17 Faster boot
    Only clear used section of EEPROM on first time boot / reset. Faster
    than clearing entire EEPROM each time.
    [nse5310-module-code.ino]
2016-07-17 Tidying
    Read encoder data into byte array, not separate bytes.
    Tidy up code.
2016-07-17 Only read four bytes
    We don’t use the 5th byte from the encoder IC, so don’t bother reading
    it
2016-07-17 Shorten WDT wait time
    [nse5310-module-code.ino]
2016-09-10 Raw encoder count
    Expose raw encoder count over I2C
2016-10-14 Add dimensions to splitter board
    [splitterBoard.PcbDoc]
2016-10-14 Mounting demo / CAD
    [mag-strip-placeholder.SLDPRT, mag-strip-support-placeholder.SLDPRT, mounting-demo-assembly.SLDASM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]
2016-10-14 Move MK2 mounting hardware to MK2 repo
    [placeholderBracket.SLDPRT, placeholderBracket.STL, xEndBracket.SLDPRT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]
2016-10-14 STM32 version
    Started messing around with this a while ago, need to commit it or lose it
    [as5311-module.GBL, as5311-module.GBO, as5311-module.GBP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]
2016-10-14 Update output files
    [nse5310-module.PcbDoc, nse5310-module.PrjPcb]
2017-02-10 Fix pin setup for AS5311
2017-02-20 Try to pack magnetic strength into unused bits in position data. Reduce transmitted position from four to three bytes (requires update on host side).
2017-03-01 Fix the data packing
    This is all that is needed to pack in the magnetic strength value since all the most significant bits are the same value as the sign bit until you get to really high values.
2017-05-31 Restructure folders, tidy up
    [Pick Place for as5311-module.csv, as5311-module.CSV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]
